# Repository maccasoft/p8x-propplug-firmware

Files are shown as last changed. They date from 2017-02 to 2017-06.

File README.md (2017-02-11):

## P8X Game System PropPlug

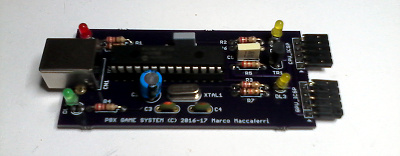
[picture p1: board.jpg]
The Board


USB programming interface for the [P8X Game System](https://dev.maccasoft.com/propgame).

Seen by the operating system as two serial ports compatible with Parallax Prop-plug.

**Windows**
 * GPU_ICSP = COM15
 * CPU_ISCP = COM16

**Linux**
 * GPU_ICSP = /dev/ttyACM0
 * CPU_ISCP = /dev/ttyACM1

_**Note:** Actual port numbers may vary depending on other USB devices plugged on the system._

**Parts List**

 * R1 = 220 ohm 1/4 watt
 * R2 = 220 ohm 1/4 watt
 * R3 = 220 ohm 1/4 watt
 * R4 = 220 ohm 1/4 watt
 * R5 = 33.000 ohm 1/4 watt
 * R6 = 10.000 ohm 1/4 watt
 * R7 = 10.000 ohm 1/4 watt
 * R8 = 10.000 ohm 1/4 watt
 * C1 = 100.000 pF poli
 * C2 = 10 uF 63v elettr.
 * C3 = 22 pF disc
 * C4 = 22 pF disc
 * C5 = 10.000 pF poli
 * DL1 = Red LED
 * DL2 = Yellow LED
 * DL3 = Yellow LED
 * DL4 = Green LED
 * XTAL1 = 12 MHz crystal
 * IC1 = PIC18F24J50
 * TR1 = Transistor BC547
 * CN1 = USB-B connector

PCBs are shared on [OSH Park](https://oshpark.com) and can be ordered from there:  
[https://oshpark.com/shared_projects/9SPZhAax](https://oshpark.com/shared_projects/9SPZhAax)

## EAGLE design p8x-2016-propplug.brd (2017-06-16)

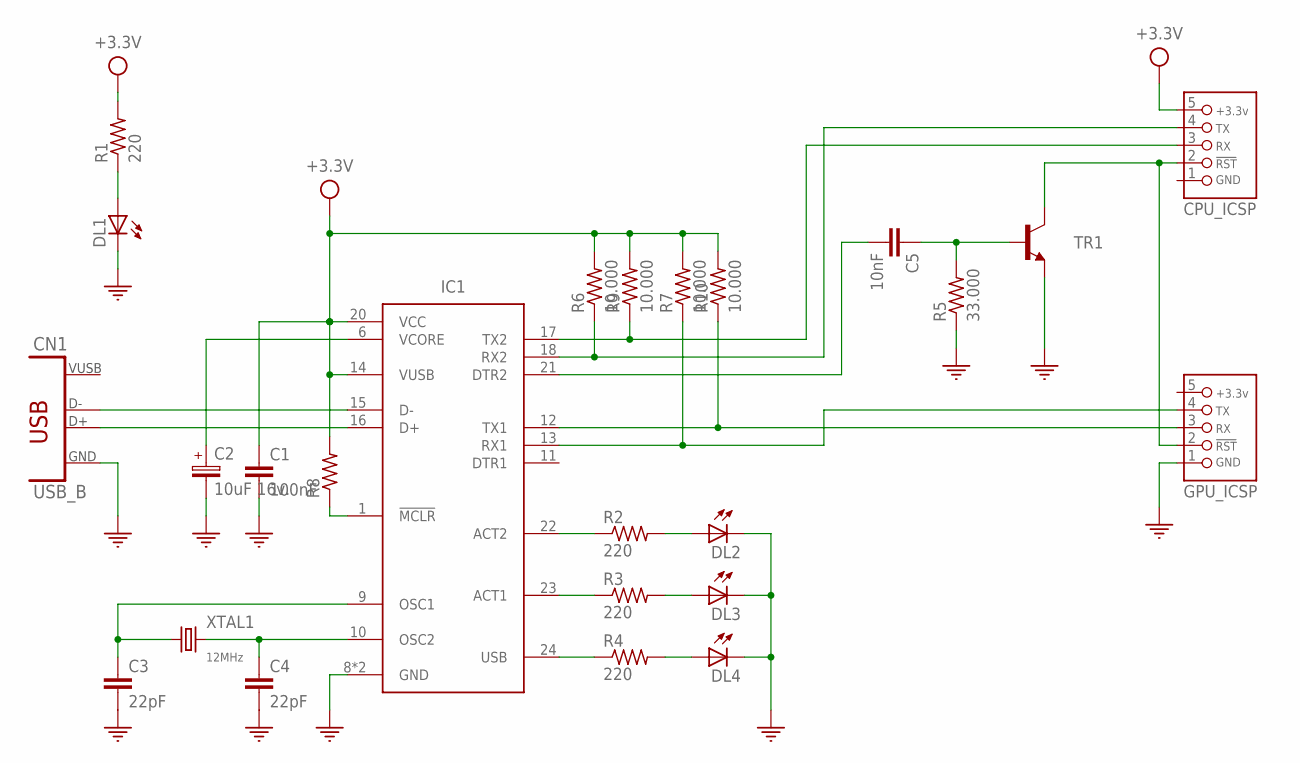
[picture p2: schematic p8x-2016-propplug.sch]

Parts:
C1: 100nF; C050-025X075
C2: 10uF 16v.; E2,5-6
C3, C4: 22pF; C050-025X075D
C5: 10nF; C050-025X075
CN1: USB_B; USB-B
CPU_ICSP: PROPELLER_ICSP_HEADER; HEADER_PRG_1X05
DL1, DL2, DL3, DL4: LED-3MM; LED3MM
GPU_ICSP: PROPELLER_ICSP_HEADER; HEADER_PRG_1X05
IC1: PIC18F24J50-I/P; DIL28
R1, R2, R3, R4: 220; 0207/10
R5: 33.000; 0207/10
R6, R7, R9, R10: 10.000; 0207/10
R8: R-1/4W; 0207/10
TR1: BC547; TO92
XTAL1: 12MHz; HC49/S

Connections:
1: CPU_ICSP.1
5: GPU_ICSP.5
!RES1!: C5.2, IC1.21 (DTR2)
+3.3V: C1.1, CPU_ICSP.5, IC1.14 (VUSB), IC1.20 (VCC), R1.2, R6.2, R7.2, R8.2, R9.2, R10.2
ACT1: IC1.23 (ACT1), R3.1
ACT2: IC1.22 (ACT2), R2.1
GND: C1.2, C2.-, C3.2, C4.2, CN1.4 (GND), DL1.K (C), DL2.K (C), DL3.K (C), DL4.K (C), GPU_ICSP.1, IC1.8 (GND), IC1.19 (GND), R5.1, TR1.1 (E)
unnamed: IC1.1 (!MCLR!), R8.1
unnamed: CN1.2 (D-), IC1.15 (D-)
unnamed: CN1.3 (D+), IC1.16 (D+)
unnamed: C4.1, IC1.10 (OSC2), XTAL1.2
unnamed: C3.1, IC1.9 (OSC1), XTAL1.1
unnamed: C5.1, R5.2, TR1.2 (B)
unnamed: DL2.A, R2.2
unnamed: DL3.A, R3.2
unnamed: C2.+, IC1.6 (VCORE)
unnamed: DL4.A, R4.2
unnamed: DL1.A, R1.1
unnamed: CPU_ICSP.2, GPU_ICSP.2, TR1.3 (C)
RX1: CPU_ICSP.4, IC1.18 (RX2), R6.1
RX2: GPU_ICSP.4, IC1.13 (RX1), R7.1
TX1: CPU_ICSP.3, IC1.17 (TX2), R9.1
TX2: GPU_ICSP.3, IC1.12 (TX1), R10.1
USB: IC1.24 (USB), R4.1
VUSB: CN1.1 (VUSB)

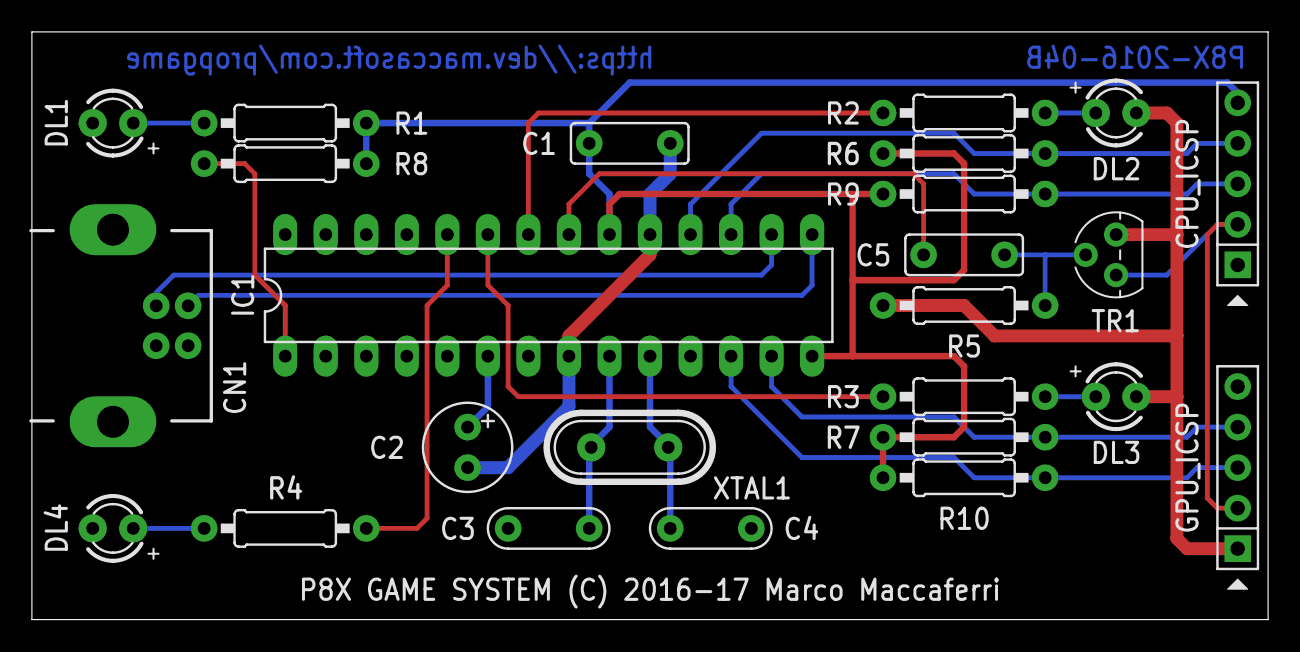
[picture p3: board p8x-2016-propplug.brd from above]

Board: 2 copper layers, 77.5 x 36.8 mm, 25 parts (0 on the bottom side), 22 nets.

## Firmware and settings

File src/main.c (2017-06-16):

/********************************************************************
 Software License Agreement:

 The software supplied herewith by Microchip Technology Incorporated
 (the "Company") for its PIC(R) Microcontroller is intended and
 supplied to you, the Company's customer, for use solely and
 exclusively on Microchip PIC Microcontroller products. The
 software is owned by the Company and/or its supplier, and is
 protected under applicable copyright laws. All rights are reserved.
 Any use in violation of the foregoing restrictions may subject the
 user to criminal sanctions under applicable laws, as well as to
 civil liability for the breach of the terms and conditions of this
 license.

 THIS SOFTWARE IS PROVIDED IN AN "AS IS" CONDITION. NO WARRANTIES,
 WHETHER EXPRESS, IMPLIED OR STATUTORY, INCLUDING, BUT NOT LIMITED
 TO, IMPLIED WARRANTIES OF MERCHANTABILITY AND FITNESS FOR A
 PARTICULAR PURPOSE APPLY TO THIS SOFTWARE. THE COMPANY SHALL NOT,
 IN ANY CIRCUMSTANCES, BE LIABLE FOR SPECIAL, INCIDENTAL OR
 CONSEQUENTIAL DAMAGES, FOR ANY REASON WHATSOEVER.
 *******************************************************************/

/** INCLUDES *******************************************************/
#include "system.h"
#include "system_config.h"

#include "app_device_cdc_basic.h"
#include "app_led_usb_status.h"

#include "usb.h"
#include "usb_device.h"
#include "usb_device_cdc.h"

/********************************************************************
 * Function:        void main(void)
 *
 * PreCondition:    None
 *
 * Input:           None
 *
 * Output:          None
 *
 * Side Effects:    None
 *
 * Overview:        Main program entry point.
 *
 * Note:            None
 *******************************************************************/
MAIN_RETURN main(void)
{
    // Map peripherals
    EECON2 = 0x55; EECON2 = 0xAA; PPSCONbits.IOLOCK = 0;
    RPINR16 = 13; // Map RP13/RC2 to USART2 RX
    RPOR12 = 5;   // Map RP12/RC1 to USART2 TX
    EECON2 = 0x55; EECON2 = 0xAA; PPSCONbits.IOLOCK = 1;

    // Configure all pins as digital ports
    ANCON0 = 0x1F;
    ANCON1 = 0x1F;
    ODCON1 = ODCON3 = 0x00;
    ODCON2 = 0b00000011;
    LATA = LATB = 0;
    LATC = 0b11000110;

    USART_Initialize();
    SYSTEM_Initialize(SYSTEM_STATE_USB_START);
    USBDeviceInit();
    USBDeviceAttach();
    
    while(1)
    {
        SYSTEM_Tasks();

        /* If the USB device isn't configured yet, we can't really do anything
         * else since we don't have a host to talk to.  So jump back to the
         * top of the while loop. */
        if( USBGetDeviceState() < CONFIGURED_STATE )
        {
            /* Jump back to the top of the while loop. */
            continue;
        }

        /* If we are currently suspended, then we need to see if we need to
         * issue a remote wakeup.  In either case, we shouldn't process any
         * keyboard commands since we aren't currently communicating to the host
         * thus just continue back to the start of the while loop. */
        if( USBIsDeviceSuspended() == true )
        {
            /* Jump back to the top of the while loop. */
            continue;
        }

        //Application specific tasks
        APP_DeviceCDCEmulatorTasks();

        USBMaskInterrupts();

        CDCTxService(0);
        CDCTxService(1);

        USBUnmaskInterrupts();

    }//end while
}//end main

bool USER_USB_CALLBACK_EVENT_HANDLER(USB_EVENT event, void *pdata, uint16_t size)
{
    switch( (int) event )
    {
        case EVENT_TRANSFER:
            break;

        case EVENT_SOF:
            /* We are using the SOF as a timer to time the LED indicator.  Call
             * the LED update function here. */
            APP_LEDUpdateUSBStatus();
            break;

        case EVENT_SUSPEND:
            /* Update the LED status for the suspend event. */
            APP_LEDUpdateUSBStatus();
            break;

        case EVENT_RESUME:
            /* Update the LED status for the resume event. */
            APP_LEDUpdateUSBStatus();
            break;

        case EVENT_CONFIGURED:
            /* When the device is configured, we can (re)initialize the 
             * demo code. */
            APP_DeviceCDCEmulatorInitialize();
            break;

        case EVENT_SET_DESCRIPTOR:
            break;

        case EVENT_EP0_REQUEST:
            /* We have received a non-standard USB request.  The HID driver
             * needs to check to see if the request was for it. */
            USBCheckCDCRequest();
            break;

        case EVENT_BUS_ERROR:
            break;

        case EVENT_TRANSFER_TERMINATED:
            break;

        default:
            break;
    }
    return true;
}

/*******************************************************************************
 End of File
*/

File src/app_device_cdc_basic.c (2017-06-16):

/********************************************************************
 Software License Agreement:

 The software supplied herewith by Microchip Technology Incorporated
 (the "Company") for its PIC(R) Microcontroller is intended and
 supplied to you, the Company's customer, for use solely and
 exclusively on Microchip PIC Microcontroller products. The
 software is owned by the Company and/or its supplier, and is
 protected under applicable copyright laws. All rights are reserved.
 Any use in violation of the foregoing restrictions may subject the
 user to criminal sanctions under applicable laws, as well as to
 civil liability for the breach of the terms and conditions of this
 license.

 THIS SOFTWARE IS PROVIDED IN AN "AS IS" CONDITION. NO WARRANTIES,
 WHETHER EXPRESS, IMPLIED OR STATUTORY, INCLUDING, BUT NOT LIMITED
 TO, IMPLIED WARRANTIES OF MERCHANTABILITY AND FITNESS FOR A
 PARTICULAR PURPOSE APPLY TO THIS SOFTWARE. THE COMPANY SHALL NOT,
 IN ANY CIRCUMSTANCES, BE LIABLE FOR SPECIAL, INCIDENTAL OR
 CONSEQUENTIAL DAMAGES, FOR ANY REASON WHATSOEVER.
 *******************************************************************/

/** INCLUDES *******************************************************/
#include "system.h"

#include <stdint.h>
#include <string.h>
#include <stddef.h>

#include "usb.h"

#include "app_led_usb_status.h"
#include "app_device_cdc_basic.h"
#include "usb_config.h"
#include "usart.h"
#include "io_mapping.h"

/** VARIABLES SERIAL 1 *********************************************/

static uint8_t USB_Out_Buffer0[CDC_DATA_OUT_EP_SIZE];
static uint8_t RS232_Out_Data0[CDC_DATA_IN_EP_SIZE];

static unsigned char  NextUSBOut0;
static unsigned char  LastRS232Out0;  // Number of characters in the buffer
static unsigned char  RS232cp0;       // current position within the buffer
static unsigned char  RS232_Out_Data_Rdy0;

/** VARIABLES SERIAL 2 *********************************************/

static uint8_t USB_Out_Buffer1[CDC_DATA_OUT_EP_SIZE];
static uint8_t RS232_Out_Data1[CDC_DATA_IN_EP_SIZE];

static unsigned char  NextUSBOut1;
static unsigned char  LastRS232Out1;  // Number of characters in the buffer
static unsigned char  RS232cp1;       // current position within the buffer
static unsigned char  RS232_Out_Data_Rdy1;


/*********************************************************************
* Function: void APP_DeviceCDCEmulatorInitialize(void);
*
* Overview: Initializes the demo code
*
* PreCondition: None
*
* Input: None
*
* Output: None
*
********************************************************************/
void APP_DeviceCDCEmulatorInitialize()
{
    CDCInitEP();

    //USART_Initialize();

    // Initialize the arrays
    unsigned char i;
	for (i=0; i<CDC_DATA_OUT_EP_SIZE; i++)
    {
		USB_Out_Buffer0[i] = 0;
        USB_Out_Buffer1[i] = 0;
    }

	NextUSBOut0 = NextUSBOut1 = 0;
	LastRS232Out0 = LastRS232Out1 = 0;
	RS232_Out_Data_Rdy0 = RS232_Out_Data_Rdy1 = 0;
}


#define mTxRdyUSART1()      PIR3bits.TX2IF
#define mTxRdyUSART2()      PIR1bits.TX1IF

#define mDataRdyUSART1()    PIR3bits.RC2IF
#define mDataRdyUSART2()    PIR1bits.RC1IF

/*********************************************************************
* Function: void APP_DeviceCDCEmulatorTasks(void);
*
* Overview: Keeps the demo running.
*
* PreCondition: The demo should have been initialized and started via
*   the APP_DeviceCDCEmulatorInitialize() and APP_DeviceCDCEmulatorStart() demos
*   respectively.
*
* Input: None
*
* Output: None
*
********************************************************************/
void APP_DeviceCDCEmulatorTasks()
{
    /* Serial 1 ****************************************************/

	if (RS232_Out_Data_Rdy0 == 0)  // only check for new USB buffer if the old RS232 buffer is
	{						      // empty.  This will cause additional USB packets to be NAK'd
		LastRS232Out0 = getsUSBUSART(0,RS232_Out_Data0,CDC_DATA_IN_EP_SIZE); //until the buffer is free.
		if(LastRS232Out0 > 0)
		{
			RS232_Out_Data_Rdy0 = 1;  // signal buffer full
			RS232cp0 = 0;  // Reset the current position
            LED_On(LED_USB_SERIAL1_ACTIVITY);
		}
	}

    // Check if one or more bytes are waiting in the physical UART transmit
    // queue.  If so, send it out the UART TX pin.
    if (RS232_Out_Data_Rdy0 && mTxRdyUSART1())
	{
        USART_putcUSART1(RS232_Out_Data0[RS232cp0]);
        ++RS232cp0;
        if (RS232cp0 == LastRS232Out0)
            RS232_Out_Data_Rdy0 = 0;
	}

    // Check if we received a character over the physical UART, and we need
    // to buffer it up for eventual transmission to the USB host.
    if (mDataRdyUSART1() && (NextUSBOut0 < (CDC_DATA_OUT_EP_SIZE - 1)))
    {
		USB_Out_Buffer0[NextUSBOut0] = USART_getcUSART1();
		++NextUSBOut0;
		USB_Out_Buffer0[NextUSBOut0] = 0;
	}

    // Check if any bytes are waiting in the queue to send to the USB host.
    // If any bytes are waiting, and the endpoint is available, prepare to
    // send the USB packet to the host.
	if ((USBUSARTIsTxTrfReady(0)) && (NextUSBOut0 > 0))
	{
		putUSBUSART(0, &USB_Out_Buffer0[0], NextUSBOut0);
		NextUSBOut0 = 0;
        LED_On(LED_USB_SERIAL1_ACTIVITY);
	}

    /* Serial 2 ****************************************************/

	if (RS232_Out_Data_Rdy1 == 0)  // only check for new USB buffer if the old RS232 buffer is
	{						      // empty.  This will cause additional USB packets to be NAK'd
		LastRS232Out1 = getsUSBUSART(1,RS232_Out_Data1,CDC_DATA_IN_EP_SIZE); //until the buffer is free.
		if(LastRS232Out1 > 0)
		{
			RS232_Out_Data_Rdy1 = 1;  // signal buffer full
			RS232cp1 = 0;  // Reset the current position
            LED_On(LED_USB_SERIAL2_ACTIVITY);
		}
	}

    // Check if one or more bytes are waiting in the physical UART transmit
    // queue.  If so, send it out the UART TX pin.
    if (RS232_Out_Data_Rdy1 && mTxRdyUSART2())
	{
        USART_putcUSART2(RS232_Out_Data1[RS232cp1]);
        ++RS232cp1;
        if (RS232cp1 == LastRS232Out1)
            RS232_Out_Data_Rdy1 = 0;
	}

    // Check if we received a character over the physical UART, and we need
    // to buffer it up for eventual transmission to the USB host.
    if (mDataRdyUSART2() && (NextUSBOut1 < (CDC_DATA_OUT_EP_SIZE - 1)))
    {
		USB_Out_Buffer1[NextUSBOut1] = USART_getcUSART2();
		++NextUSBOut1;
		USB_Out_Buffer1[NextUSBOut1] = 0;
	}

    // Check if any bytes are waiting in the queue to send to the USB host.
    // If any bytes are waiting, and the endpoint is available, prepare to
    // send the USB packet to the host.
	if ((USBUSARTIsTxTrfReady(1)) && (NextUSBOut1 > 0))
	{
		putUSBUSART(1, &USB_Out_Buffer1[0], NextUSBOut1);
		NextUSBOut1 = 0;
        LED_On(LED_USB_SERIAL2_ACTIVITY);
	}
}

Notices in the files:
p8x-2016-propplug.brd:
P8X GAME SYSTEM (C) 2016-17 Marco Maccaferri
